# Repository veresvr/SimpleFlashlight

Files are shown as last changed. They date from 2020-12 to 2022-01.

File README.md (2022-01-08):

# Simple Flashlight

This simple DIY project uses 9V battery and synchronous step-down regulator to generate the required voltage.
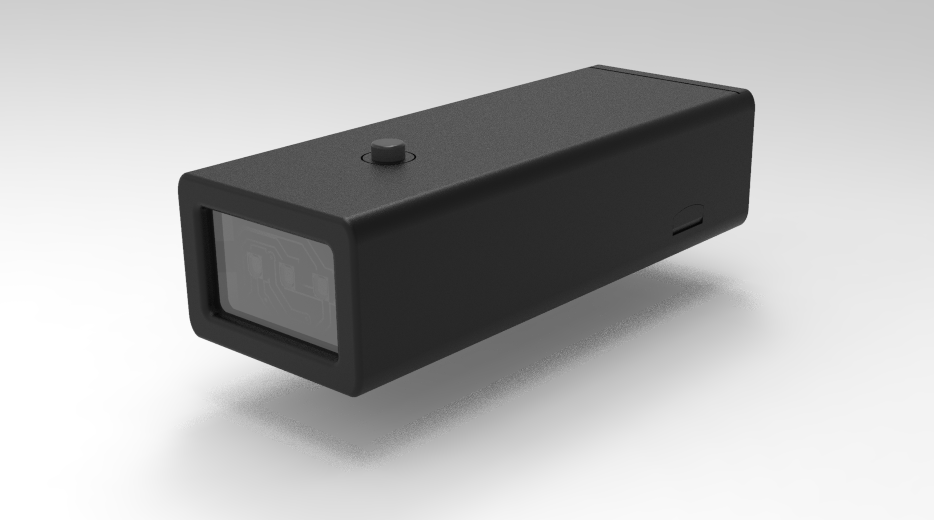
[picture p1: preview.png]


Exploded view
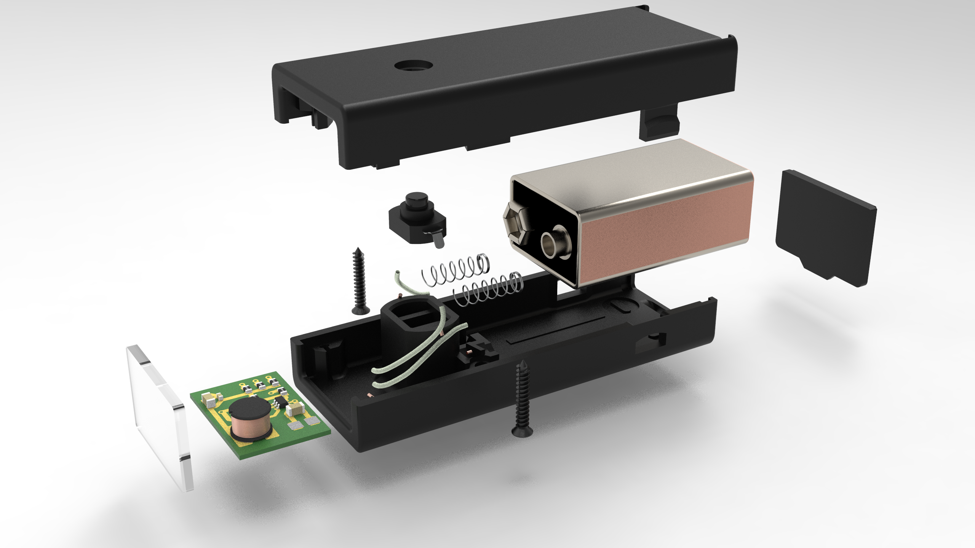
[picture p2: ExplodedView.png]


## Usage

The main assembly consist of several 3D printed parts, a pcb assembly, a switch button and other parts which are listed in  [AssemblyBOM.pdf](https://github.com/veresvr/SimpleFlashlight/tree/main/AssemblyBOM.pdf "BOM of SolidWorks assembly").
All electronics components you need for the pcb is described here [BOMforPCB.pdf](https://github.com/veresvr/SimpleFlashlight/tree/main/Electronics/BOMforPCB.pdf "BOM of Altium assembly").

The PCB design was created with Altium Designer 19. All mechanical parts and assemblies were created with SolidWorks 2020.

## Structure


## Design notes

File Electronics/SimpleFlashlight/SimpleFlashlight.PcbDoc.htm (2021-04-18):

Reporting Options

# File in Newer Format

Date | : | 4/18/2021
Time | : | 16:28:53
Filename | : | D:\development\GitHub\SimpleFlashlight\Electronics\SimpleFlashlight\SimpleFlashlight.PcbDoc

Version | Warning
Release 20.0 | CAUTION - Support of propagation delay for primitives

This file was generated by a later version of the software

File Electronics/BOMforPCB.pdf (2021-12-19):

### BOM list for Simple Flashlight Board Assembly

Designator | Description | Comment | QTY. | Manufacturer
C1 | Capacitor ceramic | 22uF | 1 | MuRata | GRM31CR61C226KE15L | 9000103922 | None
C2 | Capacitor ceramic | 1uF | 1 | MuRata | GRM188R61A105K | 886959440 | None
C3 | Capacitor ceramic | 10uF | 1 | MuRata | GRM21BR71A106KE51L | 9000122622 | None
L1 | Inductor, SMD | 10uH | 1 | Bourns | SDR0805-100ML | 246436964 | None
LED1, LED2, LED3 SMD LED | 2.8V 0.07A | 3 | ENLINCA | None | None
R1, R4, R7 | Thick Film Chip Resistor | 6.8R | 3 | Yageo | RC0805FR-076R8L | 9000079932 | None
R2 | Thick Film Chip Resistor | 12k | 1 | Yageo | RC0805FR-0712KL | 9000079516 | None
R3 | Thick Film Chip Resistor | 62k | 1 | Yageo | RC0805FR-0762KL | 9000079533 | None
R5 | Thick Film Chip Resistor | 11k | 1 | Yageo | RC0805FR-0711KL | 9000079515 | None
R6 | Thick Film Chip Resistor | 20k | 1 | Yageo | RC0805FR-0720KL | 9000079521 | None
U1 | | TPS560200DBVR | 1 | Texas Instruments | TPS560200DBVR | 9000200421 | None

Manufacturer Part
Number

Order Code
Chip&Dip

Component
Link

Aliexpress (https://aliexpress.ru/item/32975372003.html)

500mA Synchronous Step
Down Converter

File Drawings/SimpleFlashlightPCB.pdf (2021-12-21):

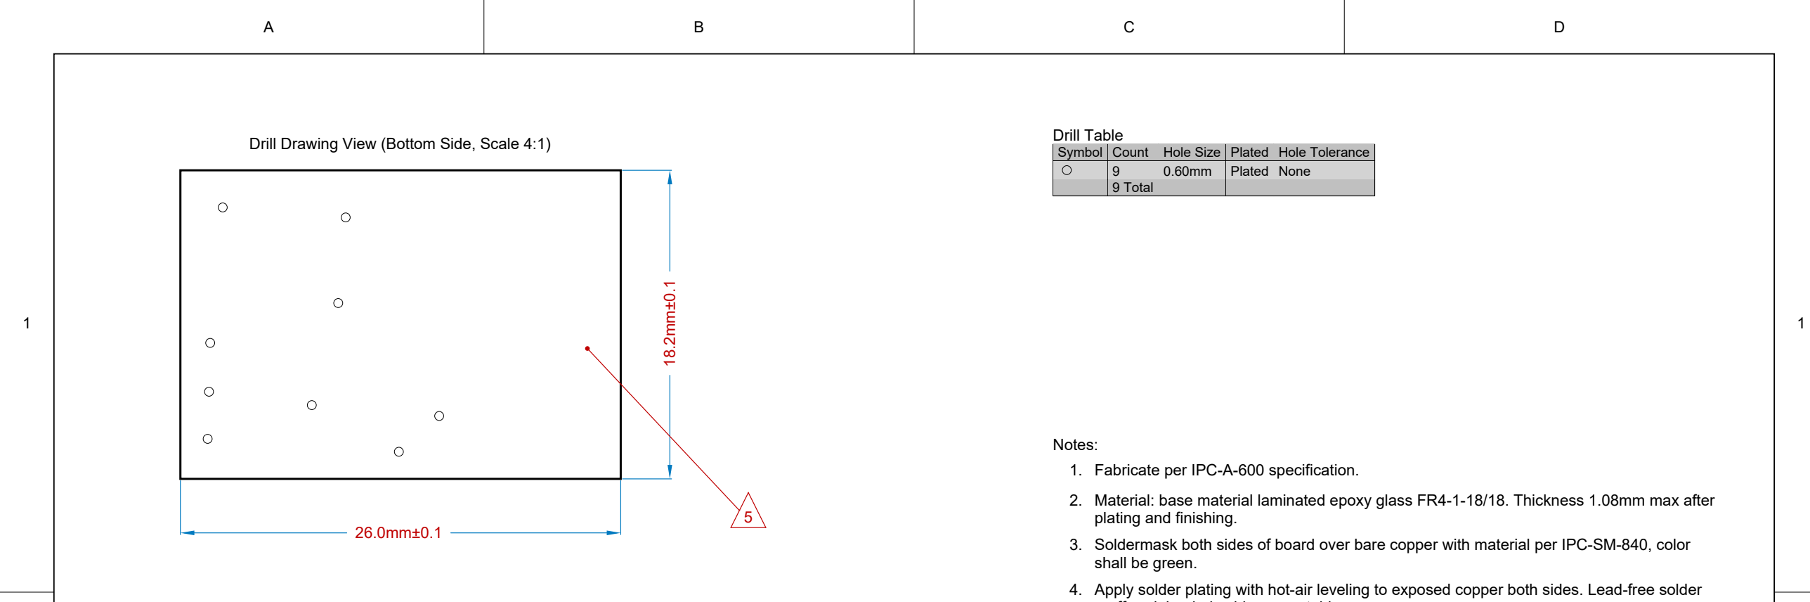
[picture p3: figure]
Symbol; Count; Hole Size; Plated; Hole Tolerance; None; 9 Total; Drill Table; plating and finishing.; shall be green.; Notes:
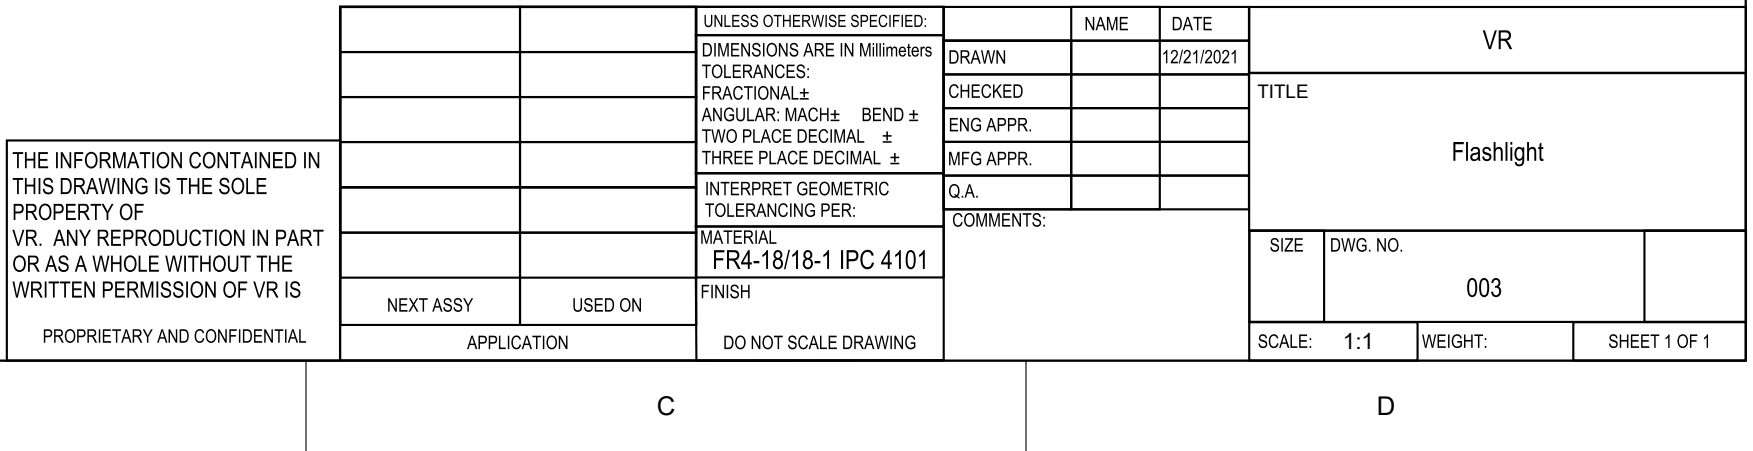
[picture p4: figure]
TITLE

A

B

2 | 2

Drill Drawing View (Bottom Side, Scale 4:1)

1. Fabricate per IPC-A-600 specification.
Material: base material laminated epoxy glass FR4-1-18/18. Thickness 1.08mm max after

Soldermask both sides of board over bare copper with material per IPC-SM-840, color

Apply solder plating with hot-air leveling to exposed copper both sides. Lead-free solder preffered; leaded solder acceptable.
Indicated area on bottom side available for application of PCB manufacture logo, UL marking, and date-code. Use of other location to be approved by purchaser. 5
6. Apply silkscreen to both sides of board using non-conductive white epoxy ink.
7. See fabrication files with same title as this drawing.
8. Outline defined in separate gerber file with ".GM1" suffix.
9. Hole locations specified in separate drill file with ".txt" suffix.
Hole sizes are specified in drill table as final dimensions after plating and finishing. All holes to be plated and under soldermask.

10.

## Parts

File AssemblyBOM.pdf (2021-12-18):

BOM list for SimpleFlashlight.SLDASM

ITEM NO. | PART NUMBER | DESCRIPTION | QTY. | Material | ComponentLink
1 | 9V Battery | 9V Battery | 1 | Multimaterial
2 | Glass | Glass | 1 | Polycarbonate (PC)
3 | Switch DC30V | 1 | Multimaterial
5 | CaseTop | Snap-fit | 1 | ABS
6 | CaseBottom | Case Bottom | 1 | ABS
7 | CaseLid | Lid | 1 | ABS
8 | Self Tapping Cross recessed Screw4Plastic | Self Tapping Screw 16mm | 2 | AISI 304
9 | PCB Assembly | PCB for flashlight | 1 | Multimaterial
10 | Wires | Wires, total lenght 60 mm | 1 | 26AWG
11 | Spring | Spring length 15mm | 2 | 302 Stainless Steel

McMaster-Carr (https://www.mcmaster.com/71455K56/)

McMaster-Carr (https://www.mcmaster.com/1749K78/)
Switch DC30V 1A | Aliexpress (https://aliexpress.ru/item/32986608335.html?spm=a2g0s.9042311.0.0.274233edmmW5Qv)
| Github (https://github.com/veresvr/SimpleFlashlight/blob/main/FilesForPrint/CaseTop.STL)
| Github (https://github.com/veresvr/SimpleFlashlight/blob/main/FilesForPrint/CaseBottom.STL)
| Github (https://github.com/veresvr/SimpleFlashlight/blob/main/FilesForPrint/Lid.STL)
| Aliexpress (https://aliexpress.ru/item/33040347870.html?spm=a2g0s.9042311.0.0.274233edM7ZVS8)
| Github (https://github.com/veresvr/SimpleFlashlight/tree/main/Electronics)
| Aliexpress (https://aliexpress.ru/item/1005001867851838.html)
| Aliexpress (https://aliexpress.ru/item/1005002654199116.html)

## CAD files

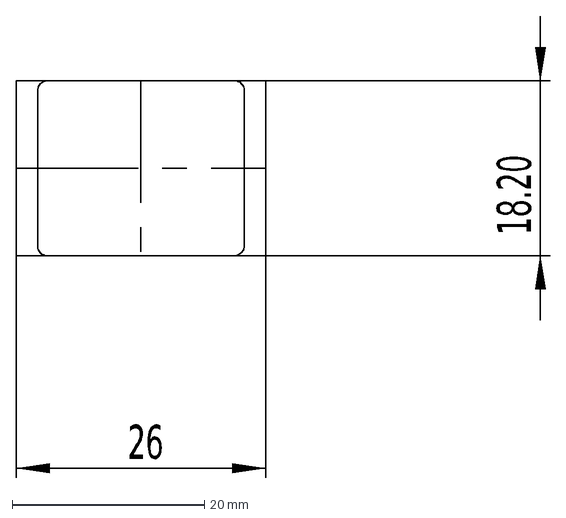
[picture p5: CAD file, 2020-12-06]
Electronics/MainPCBContour.DXF
18.20
26

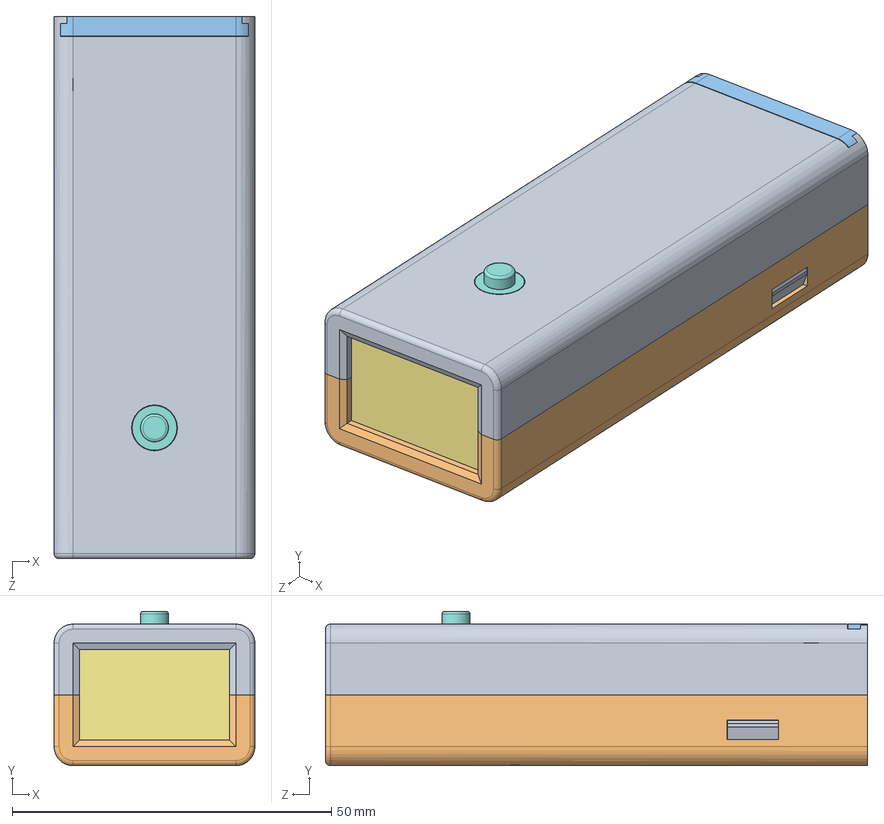
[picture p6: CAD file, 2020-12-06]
3D/SimpleLighter.SLDASM
31.5 x 24.2 x 85.0 mm
9V_Battery
Copy of PCB_simpleLighter^PCB-project_SimpleLighter
5730_SMD_LED x 4
Resistor 1206 x 4
CAP 1210-2.0mm x 3
Resistor 0805 x 4
WE-PD-7345
sot-23-5leads
CAP 0805 x 2
Barrel^Copy of PGn-nH-TH-NF_Assem1_SimpleLighter x 2
Plunger^Copy of PGn-nH-TH-NF_Assem1_SimpleLighter x 2
Copy of PCB_Connector pins^Assem1_SimpleLighter
Solder^Assem1_SimpleLighter x 2
Cross Recessed Pan Head Self-tapping Screw - no standard x 2
Glass^SimpleLighter
Virtual Switch DC30V 1A^SimpleLighter
Copy of CaseTop^Case_SimpleLighter
Copy of CaseBottom^Case_SimpleLighter
Copy of Lid1^Case_SimpleLighter

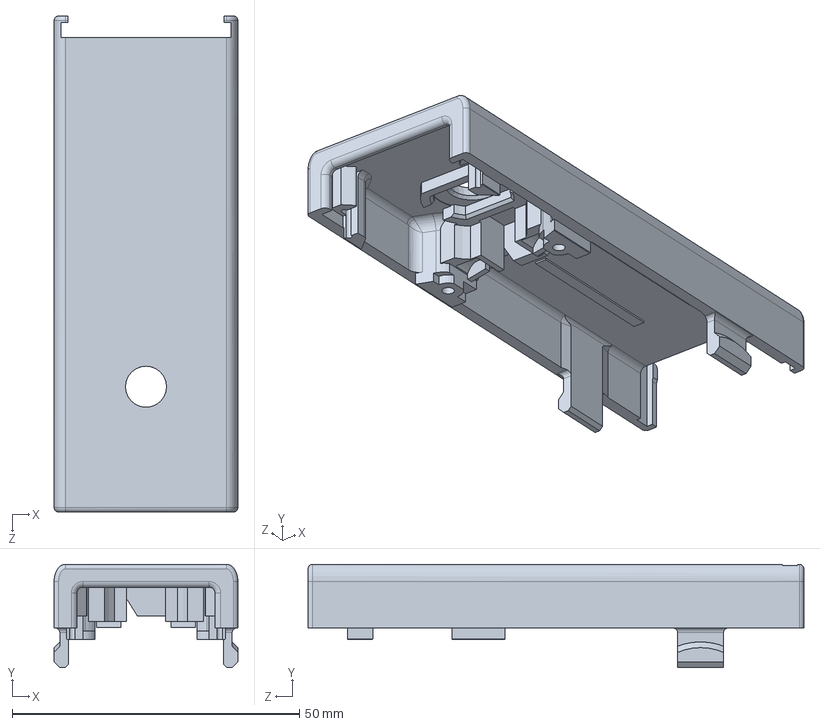
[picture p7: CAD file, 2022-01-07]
3D/CaseTop.SLDPRT
32.0 x 18.0 x 86.3 mm

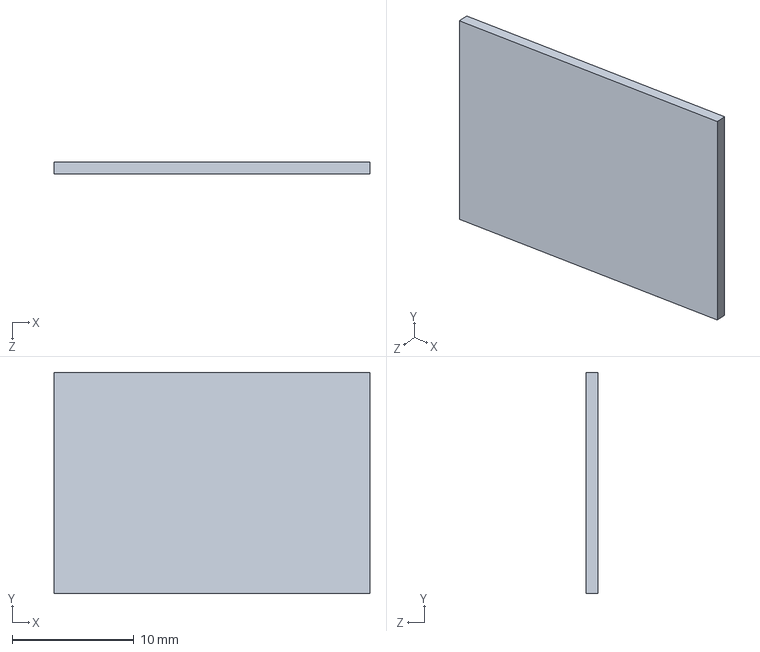
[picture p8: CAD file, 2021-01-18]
Electronics/SimpleFlashlight/Board-Part-1.SLDPRT
26.0 x 18.2 x 0.96 mm

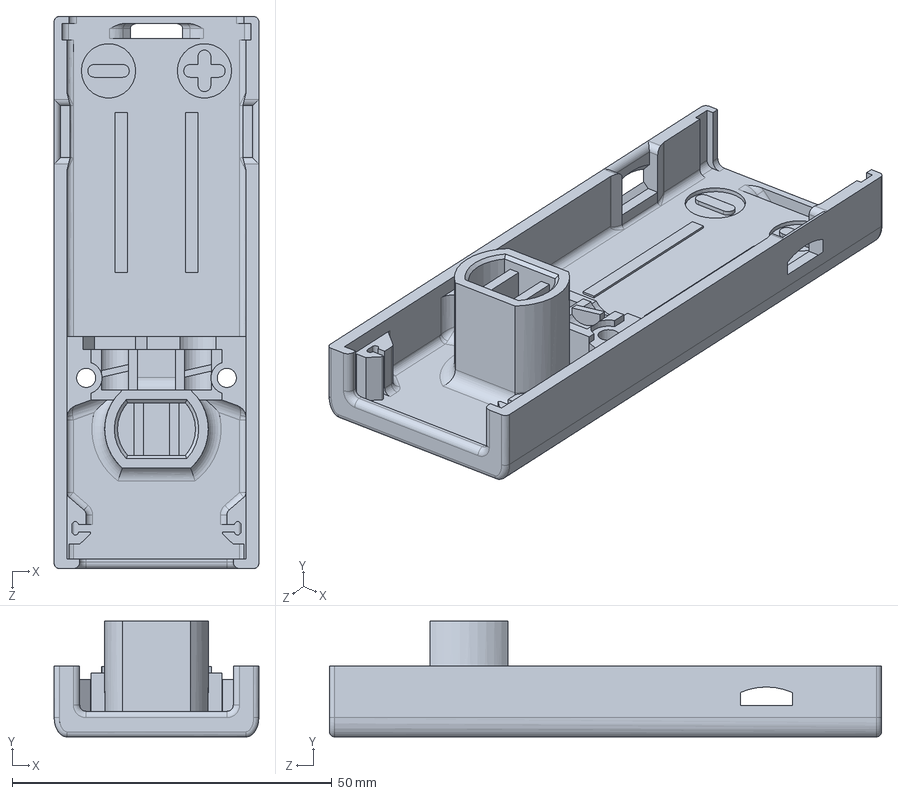
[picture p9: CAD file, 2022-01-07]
3D/CaseBottom.SLDPRT
32.0 x 18.1 x 86.3 mm

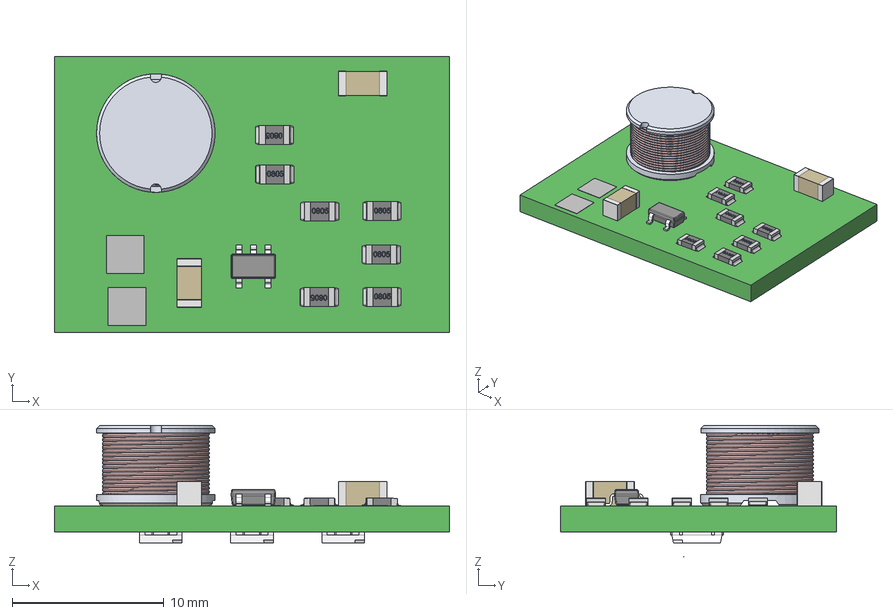
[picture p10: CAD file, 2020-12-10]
Electronics/SimpleFlashlight/SimpleFlashlight.step
26.0 x 18.2 x 8.63 mm
Board
Extruded x 2
CAP_1206 x 2
C2
SDR0805-100ML-BOURNS
DBV0005A_2
DBV0005A_1 x 5

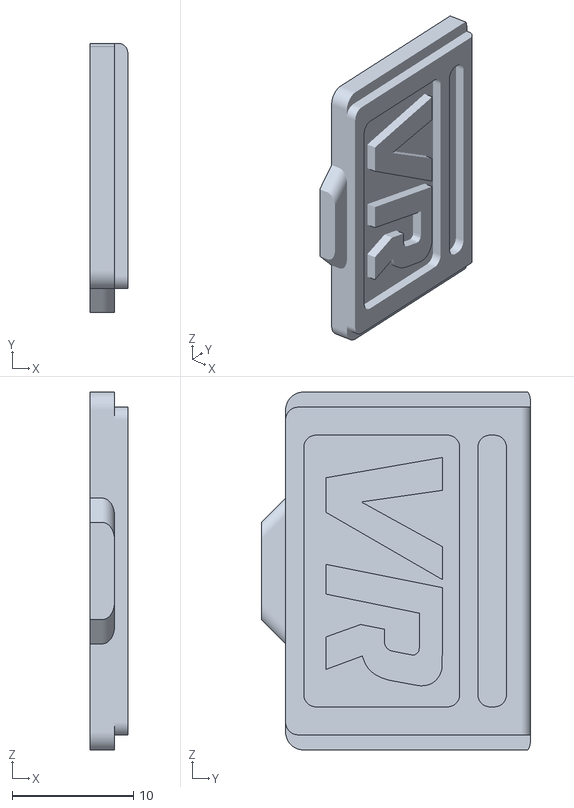
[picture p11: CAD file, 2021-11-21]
FilesForPrint/Lid.STL
3.10 x 22.2 x 29.5

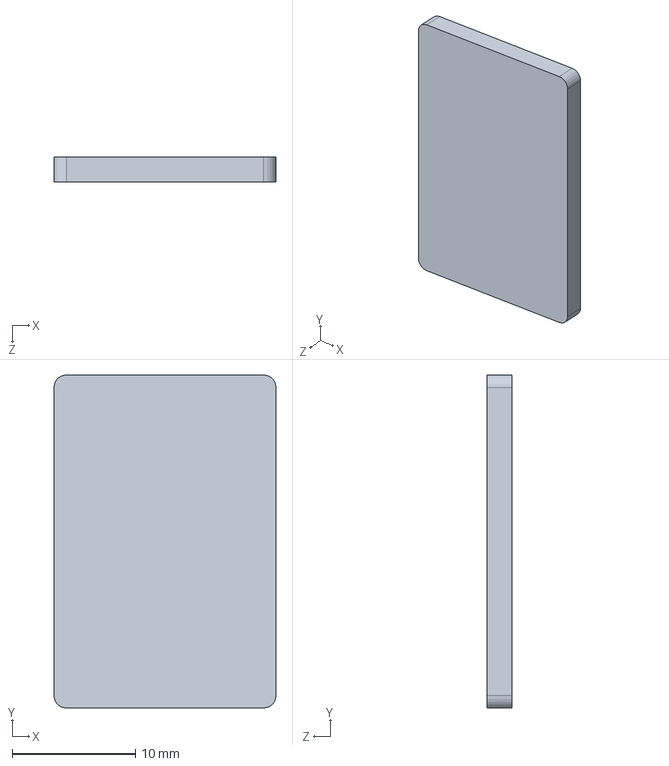
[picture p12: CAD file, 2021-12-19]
3D/Glass.SLDPRT
18.0 x 27.0 x 2.00 mm

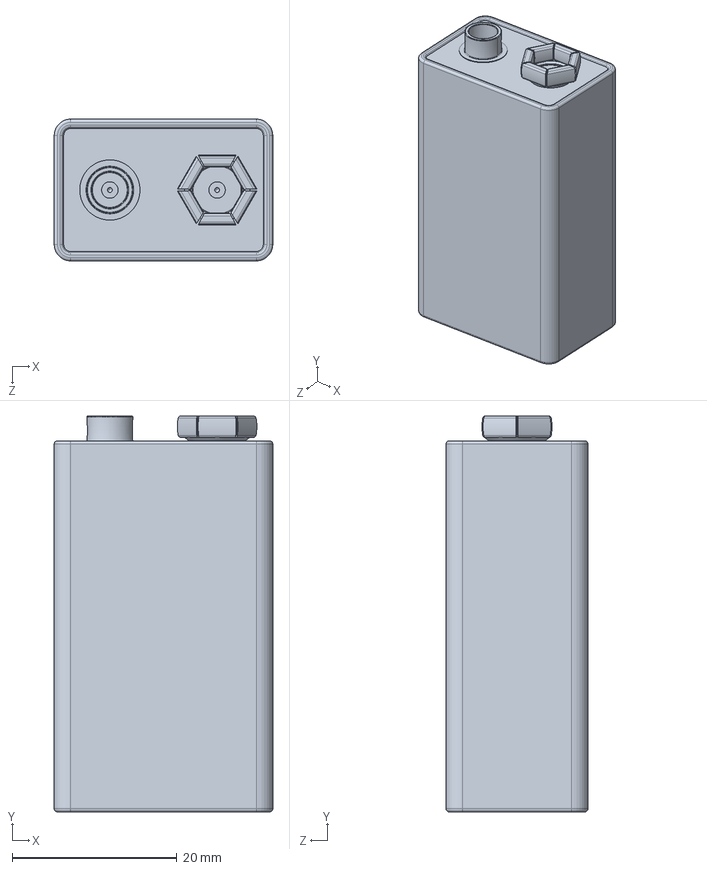
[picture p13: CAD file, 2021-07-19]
3D/9V_Battery.SLDPRT
26.5 x 48.0 x 17.2 mm

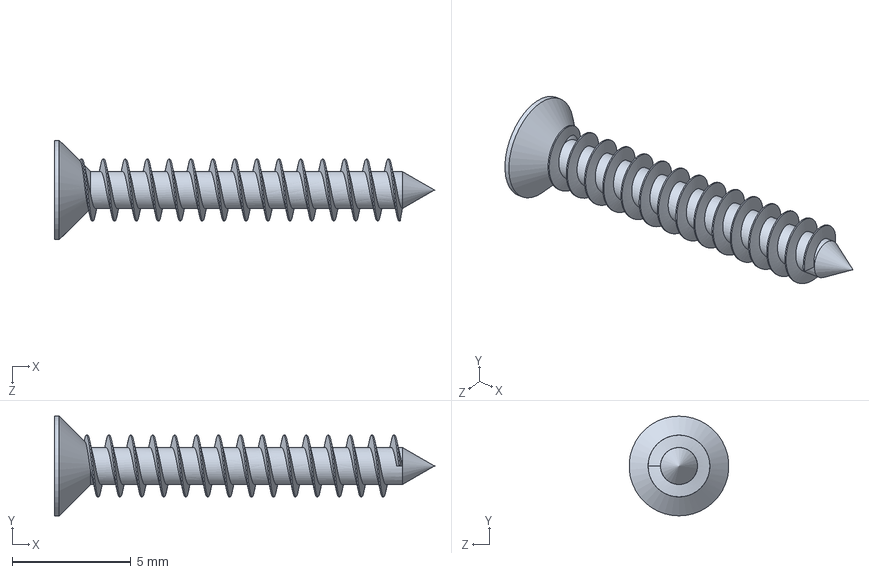
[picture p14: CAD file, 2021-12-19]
3D/Self Tapping Cross recessed Screw 4Plastic.SLDPRT
16.0 x 4.20 x 4.19 mm

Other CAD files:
FilesForPrint/CaseTop.STL
CaseBottom.STL
Drawings/CaseBottom.SLDDRW
Drawings/CaseTop.SLDDRW
Drawings/Glass.SLDDRW
Drawings/SimpleFlashlight.SLDDRW
Electronics/MainPCBContour.SLDDRW
Electronics/SimpleFlashlight/SimpleFlashlight.x_t

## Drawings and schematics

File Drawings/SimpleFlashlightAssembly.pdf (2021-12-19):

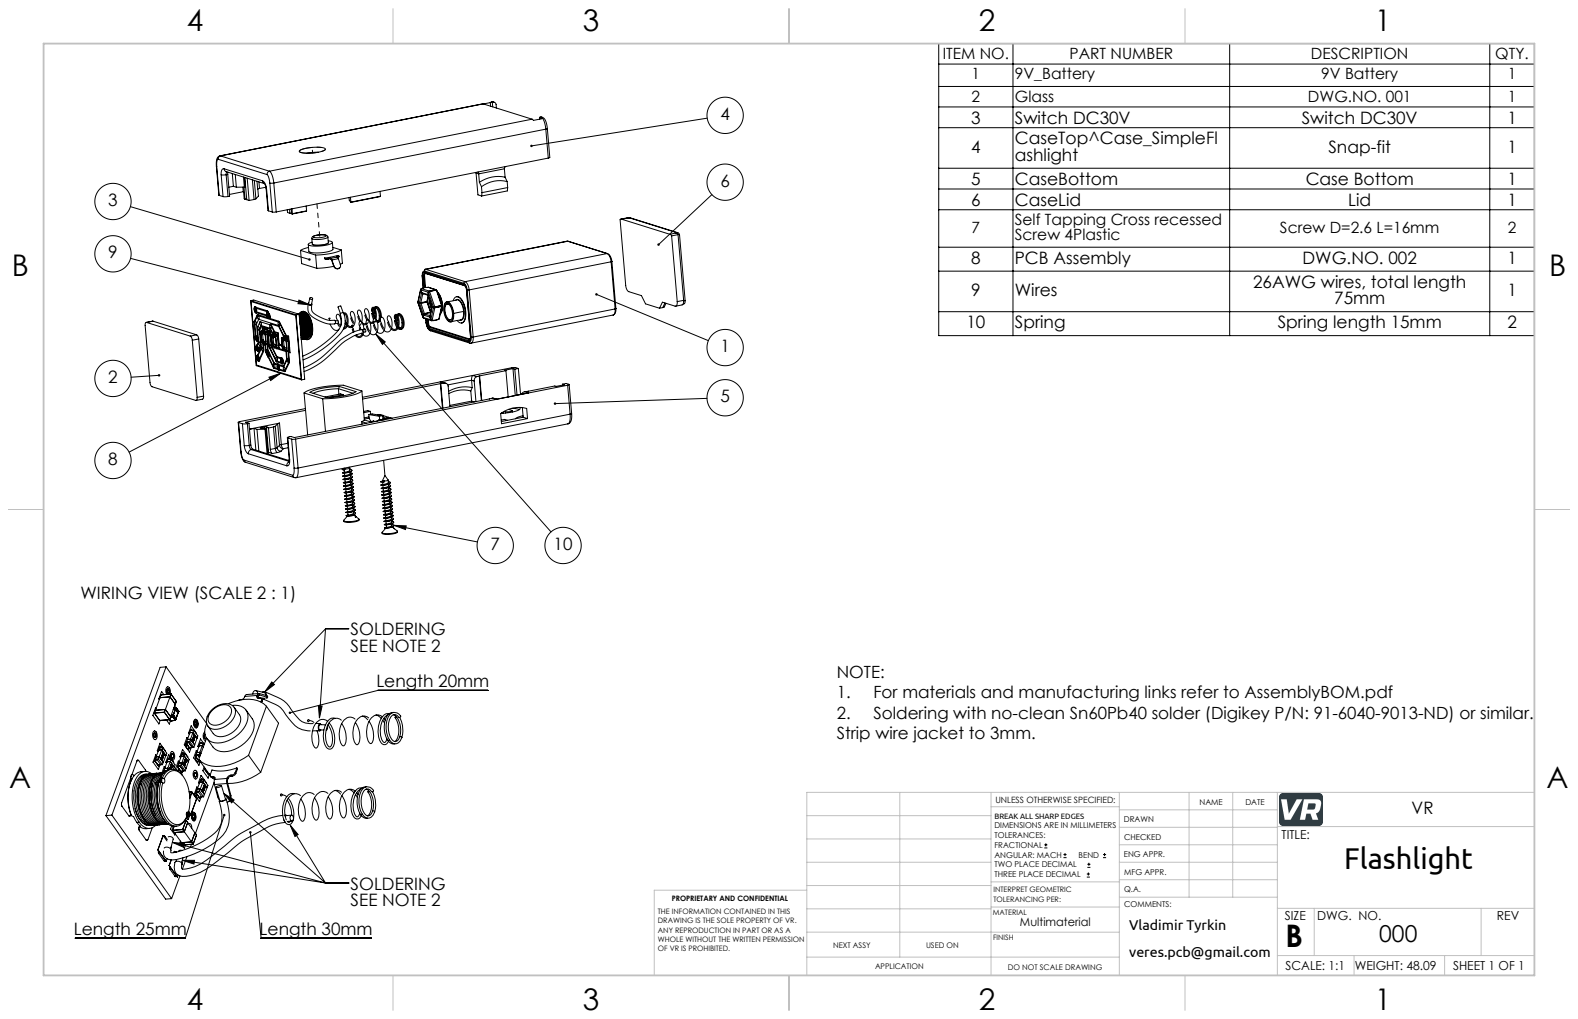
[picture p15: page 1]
SEE NOTE 2; Length 20mm; Length 25mm; Length 30mm

ITEM NO. | PART NUMBER | DESCRIPTION | QTY.
1 | 9V_Battery | 9V Battery | 1
2 | Glass | DWG.NO. 001 | 1
3 | Switch DC30V | Switch DC30V | 1
4 | CaseTop^Case_SimpleFl ashlight | Snap-fit | 1
5 | CaseBottom | Case Bottom | 1
6 | CaseLid | Lid | 1
7 | Self Tapping Cross recessed Screw 4Plastic | Screw D=2.6 L=16mm | 2
8 | PCB Assembly | DWG.NO. 002 | 1
9 | Wires | 26AWG wires, total length 75mm | 1
10 | Spring | Spring length 15mm | 2

WIRING VIEW (SCALE 2 : 1)

NOTE:
1. For materials and manufacturing links refer to AssemblyBOM.pdf
2. Soldering with no-clean Sn60Pb40 solder (Digikey P/N: 91-6040-9013-ND) or similar.
Strip wire jacket to 3mm.

UNLESS OTHERWISE SPECIFIED: | | DATE | VR NAME
BREAK ALL SHARP EDGES DIMENSIONS ARE IN MILLIMETERS TOLERANCES: FRACTIONAL ANGULAR: MACH BEND TWO PLACE DECIMAL THREE PLACE DECIMAL | DRAWN

CHECKED | | TITLE: Flashlight

ENG APPR.
MFG APPR.

INTERPRET GEOMETRIC TOLERANCING PER: | Q.A.
MATERIAL Multimaterial | | SIZE B | DWG. NO. 000 | REV

PROPRIETARY AND CONFIDENTIAL
THE INFORMATION CONTAINED IN THIS
DRAWING IS THE SOLE PROPERTY OF VR.
ANY REPRODUCTION IN PART OR AS A
WHOLE WITHOUT THE WRITTEN PERMISSION
OF VR IS PROHIBITED.

COMMENTS:
Vladimir Tyrkin
veres.pcb@gmail.com

NEXT ASSY | USED ON | FINISH

APPLICATION | DO NOT SCALE DRAWING | | SCALE: 1:1 | WEIGHT: 48.09 | SHEET 1 OF 1

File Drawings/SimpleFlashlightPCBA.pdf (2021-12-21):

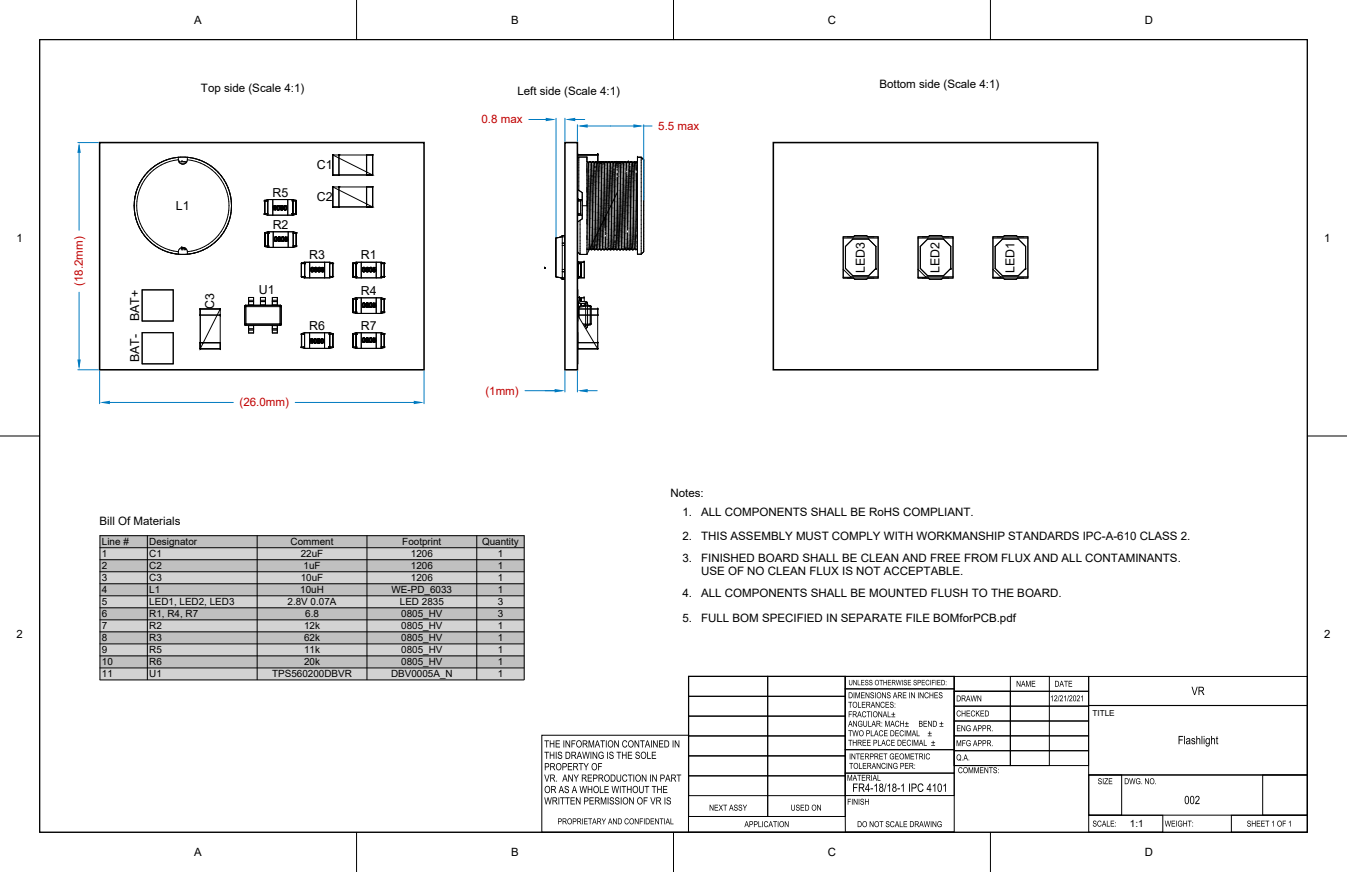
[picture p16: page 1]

Notes:
1. ALL COMPONENTS SHALL BE RoHS COMPLIANT.

2. THIS ASSEMBLY MUST COMPLY WITH WORKMANSHIP STANDARDS IPC-A-610 CLASS 2.
FINISHED BOARD SHALL BE CLEAN AND FREE FROM FLUX AND ALL CONTAMINANTS.
USE OF NO CLEAN FLUX IS NOT ACCEPTABLE.
4. ALL COMPONENTS SHALL BE MOUNTED FLUSH TO THE BOARD.

5. FULL BOM SPECIFIED IN SEPARATE FILE BOMforPCB.pdf

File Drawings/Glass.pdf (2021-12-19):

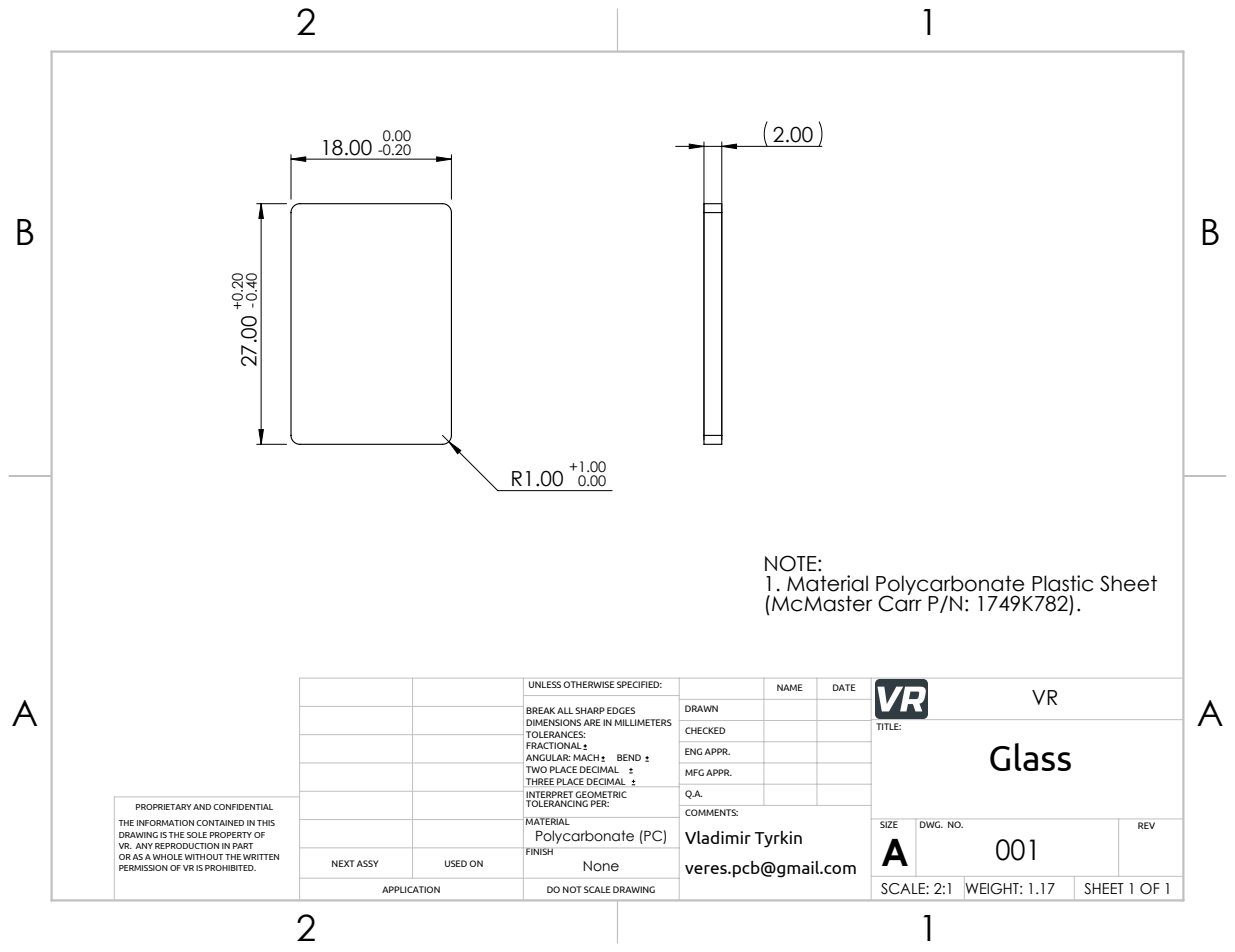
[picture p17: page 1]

NOTE:
1. Material Polycarbonate Plastic Sheet
(McMaster Carr P/N: 1749K782).

UNLESS OTHERWISE SPECIFIED: | | DATE | VR NAME

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

CHECKED | | TITLE: Glass

ENG APPR.

MFG APPR.

INTERPRET GEOMETRIC TOLERANCING PER: | Q.A.
MATERIAL Polycarbonate (PC) | | SIZE A | DWG. NO. 001 | REV

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

COMMENTS:
Vladimir Tyrkin
veres.pcb@gmail.com

NEXT ASSY | USED ON | FINISH None

APPLICATION | DO NOT SCALE DRAWING | | SCALE: 2:1 | WEIGHT: 1.17 | SHEET 1 OF 1

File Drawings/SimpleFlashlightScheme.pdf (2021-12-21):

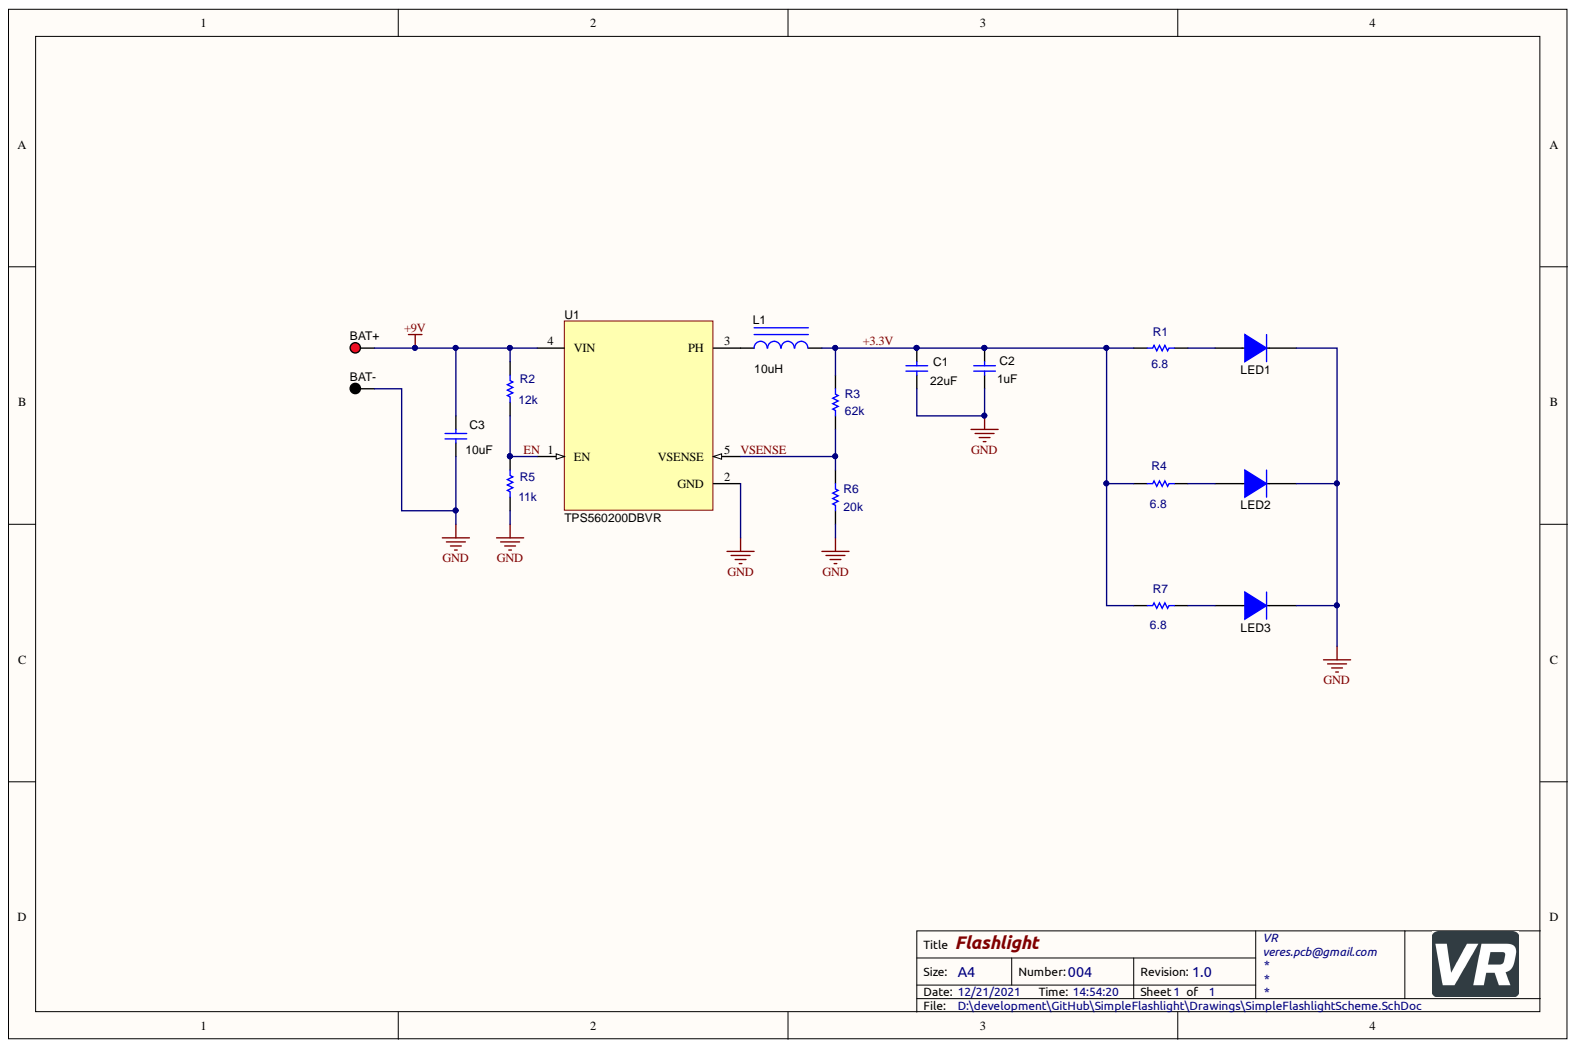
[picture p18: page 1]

Flashlig h t | VR veres.p cb@g m ail. com ** *

A4 | 004 m ber : | 1. 0 Rev isi o n :
12/21/2021 Ti me: 14:54:20 | | S heet 1 o f 1
D:\ develo p ment\GitH u b \ S i m pleFlashli g ht\Draw i n gs\ S i m pleFlashli g htS c heme. S c hDo | c

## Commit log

2020-12-01 Update assembly
    Add some new parts
    [5730_SMD_LED.SLDPRT, 9V_Battery.SLDPRT, CAP 0805.SLDPRT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]
2020-12-01 Added lock slot
    [SimpleLighter.SLDASM]
2020-12-03 Second lock mechanism
    Added second lock mechanism
    [SimpleLighter.SLDASM]
2020-12-03 Update joints
    Add 2 snap-fit joints and mount holes
    [SimpleLighter.SLDASM]
2020-12-04 Little changes
    [SimpleLighter.SLDASM]
2020-12-04 Added library with electronics
    [SimpleFlashlight.PrjPcb, SimpleFlashlight.SchDoc]
2020-12-05 Update scheme and create PCB
    [SimpleFlashlight.PcbDoc, SimpleFlashlight.PrjPcb, SimpleFlashlight.SchDoc]
2020-12-06 A little changes in scheme
    [SimpleFlashlight.PcbDoc, SimpleFlashlight.PrjPcb, SimpleFlashlight.SchDoc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]
2020-12-06 Changed PCBs thickness, slots for
2020-12-06 Almost done the case
    [Cross Recessed Pan Head Self-tapping Screw - no standard.SLDPRT]
2020-12-06 Import contour PCB from SolidWorks to Altium. Add some 3D models to project library. Create room. Update rules
    [MainPCBContour.DXF, MainPCBContour.SLDDRW, SimpleFlashlight.PcbDoc]
2020-12-06 Component placement in PCB
    [MainPCBContour.SLDDRW, SimpleFlashlight.PcbDoc]
2020-12-08 Update PCB and main assembly
    [SimpleFlashlight.PcbDoc, SimpleFlashlight.SchDoc, SimpleFlashlight.x_t]
2020-12-09 Update DRC with recommended values from JLCPCB. Finally made PCB tracing.
    [SimpleFlashlight.PcbDoc]
2020-12-10 Add another type of LEDs
    [SimpleFlashlight.PcbDoc, SimpleFlashlight.PrjPcb, SimpleFlashlight.SchDoc]
2020-12-10 Update Assembly with new PCB
    [SimpleFlashlight.PcbDoc, SimpleFlashlight.step, SimpleFlashlight.x_t]
2020-12-10 A little changes in assembly with tolerances.
    [SimpleFlashlight.PcbDoc, SimpleFlashlight.PrjPcb]
2020-12-14 Changed a little bit snap-fitting hook for ability 3D printing
2020-12-14 Changed screw type & add some fillets
2021-01-06 Updated assembly to SW2020. Some changes of Lid for best fit in real product.
    [9V_Battery.SLDPRT]
2021-01-06 Some little changes for cases
    [9V_Battery.SLDPRT]
2021-01-08 Prototype v.1
2021-01-13 Changed dimensions of switch, also changed a little bit top and bottom case.
2021-01-14 Added compression strip for top part of case
2021-01-17 Cosmetic changes in PCB
    [SimpleFlashlight.PcbDoc, SimpleFlashlight.SchDoc]
2021-01-18 Decreased PCBs thickness to 1mm, updated case for that width. Added some wires
    [Board-Part-1.SLDPRT, SimpleFlashlight.PcbDoc, SimpleFlashlight.PrjPcb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]
2021-01-20 Updated screws, case. Added some wires.
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2021-01-25 Modified slots for PCBs, screw holes, some fillets.
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2021-02-24 A little updates in board
    [SimpleFlashlight.PcbDoc, SimpleFlashlight.PrjPcb]
2021-02-25 Done with the scheme
    [SimpleFlashlight.PcbDoc, SimpleFlashlight.PrjPcb, SimpleFlashlight.SchDoc]
2021-04-18 Updated layers in the pcb
    [SimpleFlashlight.PcbDoc, SimpleFlashlight.PrjPcb]
2021-05-05 Has done with sch and pcb libraries, updated scheme and pcb. Made BOM list
    [SimpleFlashlight.PcbDoc, SimpleFlashlight.PcbLib, SimpleFlashlight.PrjPcb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]
2021-06-08 Added another configuration to the main assembly for trying to make more technological geometry. Fixed some little bugs in the pcb
    [SimpleFlashlight.PrjPcb]
2021-07-08 Replaced chamfer to fillet at the face of flashlight. Updated the slider-slot configuration: added 0.5 mm to the slider thickness and chamfers to each sides.
2021-07-08 Added fillets in the corner to the snap-fit mechanism for both lids. Reduced 1mm slot for the glass to 0.4mm. Corrected the back Lid a bit. Updated some parameters in parts.
2021-07-09 Updated the slot for the back Lid. Updated the width of back Lid and added more fillets. Redrawn slot for the board.
2021-07-13 Added springs instead of connection pins. Removed pcb slots. Updated geometry for springs placed
2021-07-16 Changed slots for the pcb. Added locking mechanism to springs. Checked interferences.
2021-07-16 Updated wires. Added a few fillets.
2021-07-17 Finished with cables. Updated parts properties. Updated the lid. Added 2 configurations: production and design. Updated the preview file. Generated files for printing
    [CaseBottom.STL, CaseTop.STL, Lid.STL]
2021-07-18 Prototype v.2.
    [CaseTop.STL, Lid.STL]
2021-07-18 Updated links in parts. Changed location for production files
    [CaseTop.STL, Lid.STL]
2021-07-19 Updated properties in parts. Updated .stl model. Made drawing for the glass.
    [9V_Battery.SLDPRT, CaseTop.STL, Glass.SLDDRW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]
2021-07-20 Created and added exploded view into the drawing.
    [SimpleFlashlight.SLDDRW]
2021-07-20 Added the draftsman document
    [SimpleFlashlight.PrjPcb]
2021-11-21 Updated production geometry in the top case (added a fillet). Updated all parts for production.
    [CaseTop.STL, Lid.STL]
2021-12-18 Updated preview picture. Updated the assembly drawing.
    [5730_SMD_LED.SLDPRT, CAP 0805.SLDPRT, CAP 1210-2.0mm.SLDPRT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]
2021-12-18 Updated parameters for electronic components.
    [SimpleFlashlight.PcbDoc, SimpleFlashlight.SchDoc]
2021-12-19 Updated the readme. Added the PCB BOM.
2021-12-19 Updated drawings
    [Glass.SLDDRW, Glass.SLDPRT, Self Tapping Cross recessed Screw 4Plastic.SLDPRT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]
2021-12-19 Added scheme drawing, updated mechanical drawings.
    [SimpleFlashlight.PrjPcb, SimpleFlashlight.SLDDRW, SimpleFlashlight.SchDoc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]
2021-12-19 Updated the board drawing
2021-12-21 Updated all drawings.
    [SimpleFlashlight.PcbDoc, SimpleFlashlight.PrjPcb, SimpleFlashlightScheme.SchDoc]
2022-01-07 Updated the main assembly. Added drawings.
    [CaseBottom.SLDDRW, CaseBottom.SLDPRT, CaseTop.SLDDRW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]
2022-01-07 Updated the joint geometry. Updated the production files
    [CaseBottom.SLDPRT, CaseTop.SLDPRT, CaseTop.STL]
